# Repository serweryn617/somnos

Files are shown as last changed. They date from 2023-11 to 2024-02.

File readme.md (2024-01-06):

# Somnos

IoT USB power measurement and on/off switch.

---

The device has USB C input and standard USB A output.

It is capable of measuring USB bus voltage, current and power as well as switching the power on and off.

When requested, the measurement result can be sent over ethernet (UDP) to a receiver, for example to a PC.

⚠️ Power consumed by the device itself is also included in this measurement, which may be unwanted in some use cases.

# Building Firmware

Setup build environment:

```bash
./project.py submodules
./project.py setup
```

Build the project:

```bash
./project.py build
```

# Hardware Used

- Raspberry Pi Pico microcontroller,
- INA219 I2C Current/Power Monitor breakout board,
- Enc28J60 Ethernet Controller board,
- MOSFET breakout board,
- Custom breakout PCB,
- 3D printed enclosure and 4 M3x8 screws.

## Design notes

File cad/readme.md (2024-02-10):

# Somnos CAD Files

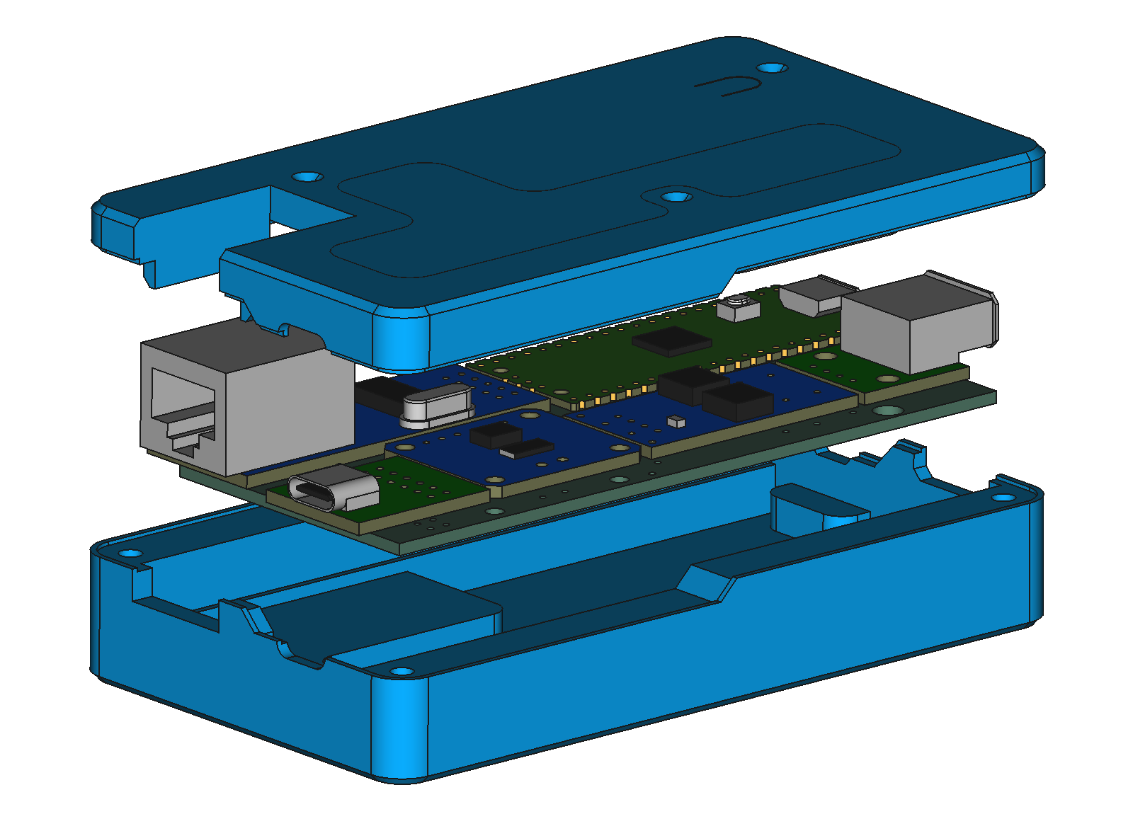
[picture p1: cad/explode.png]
explode


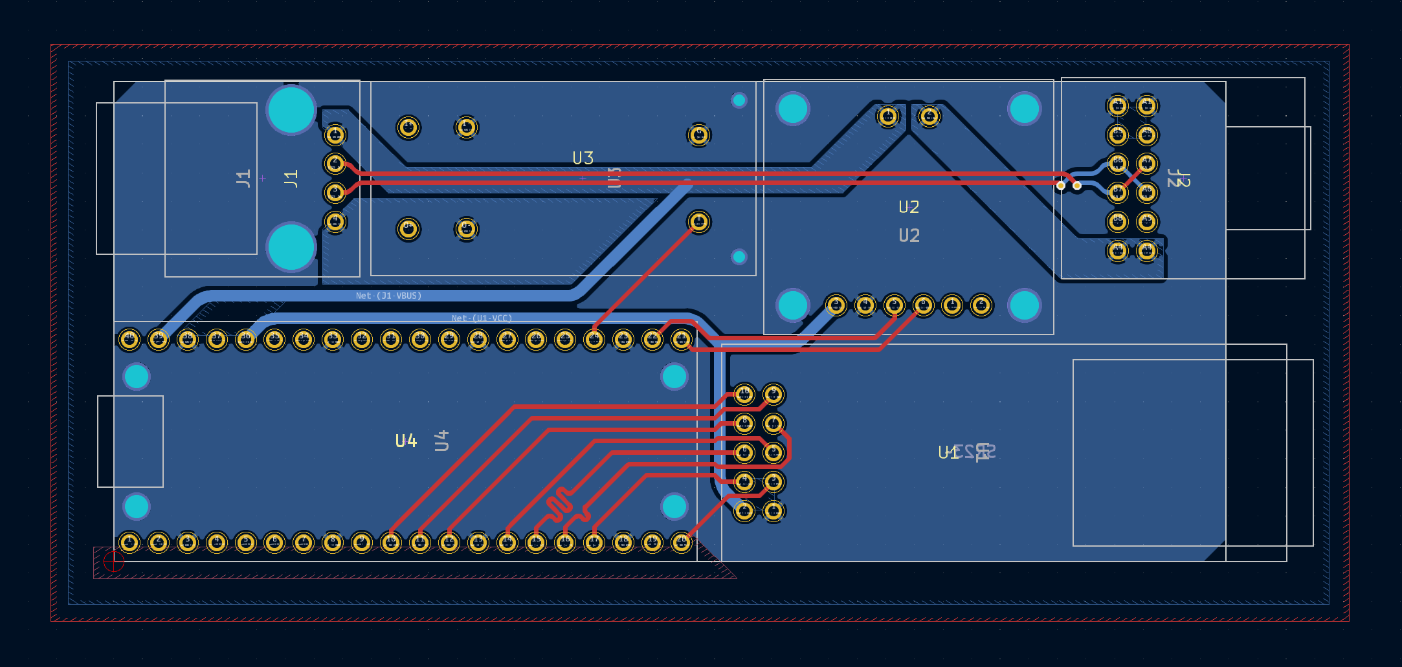
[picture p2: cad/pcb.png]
pcb


---

Initial PCB prototype notes:
 - resistors missing on USB-C CC pins!
 - update INA219 footprint so it better matches the module,
 - disconnect clkout pin - unused ethernet module output pin.

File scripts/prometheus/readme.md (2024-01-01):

# Example Prometheus Scripts

Scripts that can be used to automatically get data from the device and prepare it for [Prometheus](https://prometheus.io/).

## Usage

Display power data manually:

```bash
python3 get_power.py
```

---

Measure power every 15s using cron:

Edit crontab:

```bash
crontab -e
```

Add the following entry:

```bash
* * * * * <script path>/power.sh
```

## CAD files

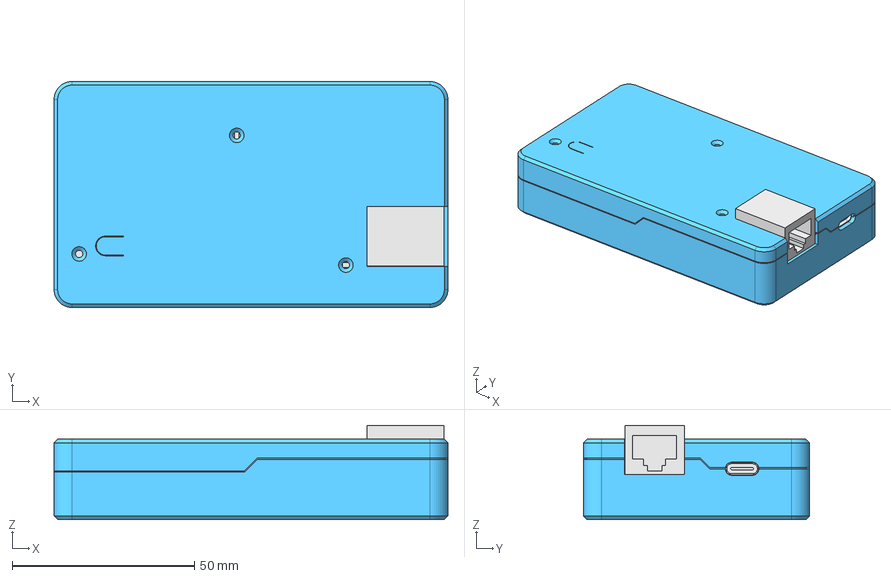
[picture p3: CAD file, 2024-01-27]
cad/freecad/assembly.FCStd
108.0 x 62.0 x 25.8 mm
pcb1_001
bottom_housing_v1.1_001
usba_001
usbc_001
ina219_001
nmos_001
enc_001
pico_001
top_housing_001
top_modifier_001

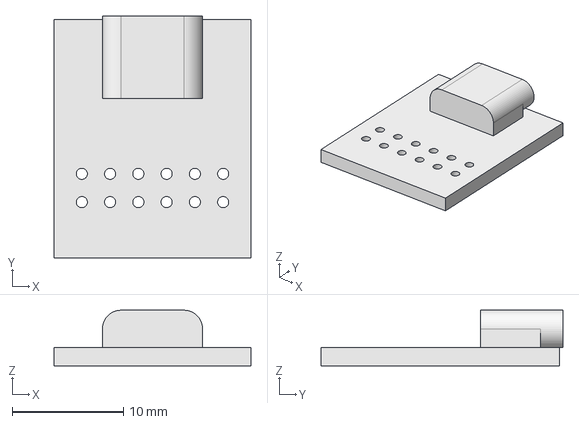
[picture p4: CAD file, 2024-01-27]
cad/freecad/usbc.FCStd
17.7 x 21.7 x 5.00 mm

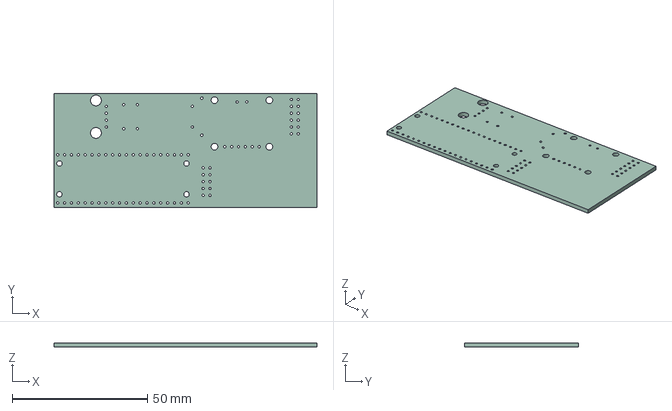
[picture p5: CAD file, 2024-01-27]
cad/kicad/project/pcb.step
97.2 x 42.0 x 1.60 mm

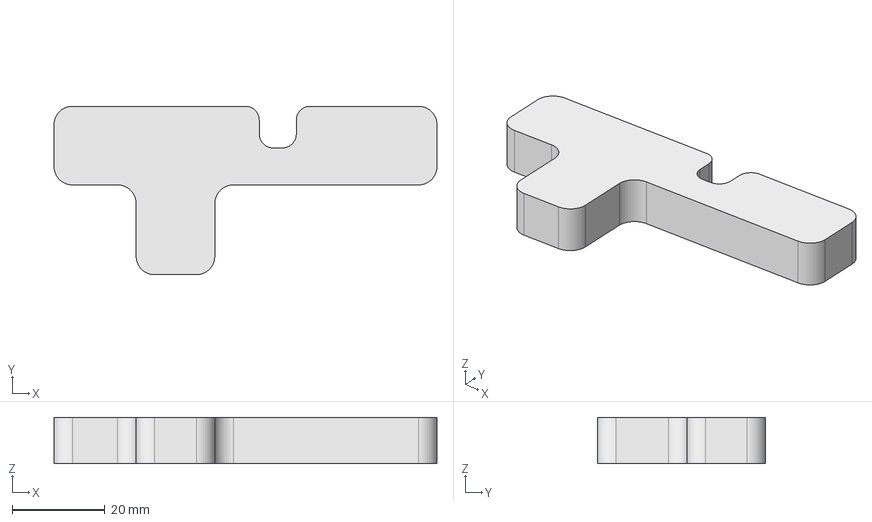
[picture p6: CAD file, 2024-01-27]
cad/top_housing_modifier.step
82.8 x 36.4 x 10.0 mm

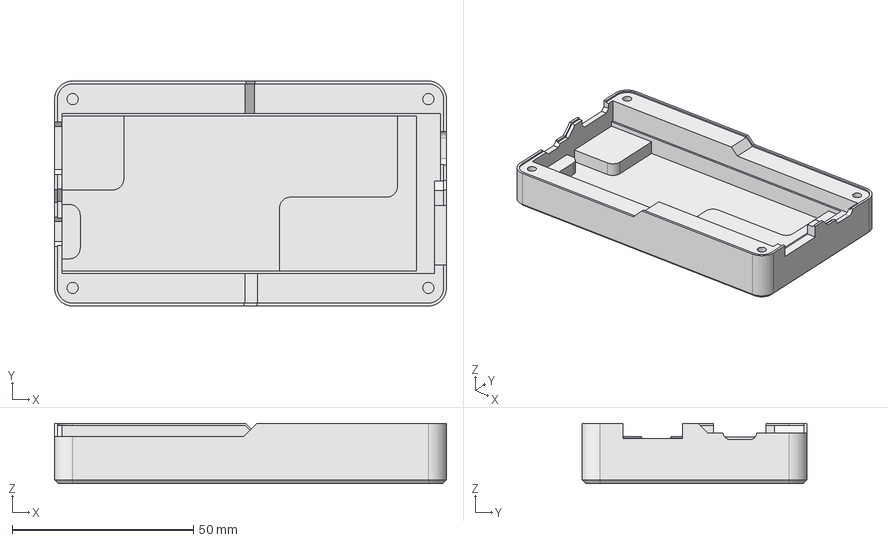
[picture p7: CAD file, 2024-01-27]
cad/bottom_housing.step
108.0 x 62.0 x 16.5 mm

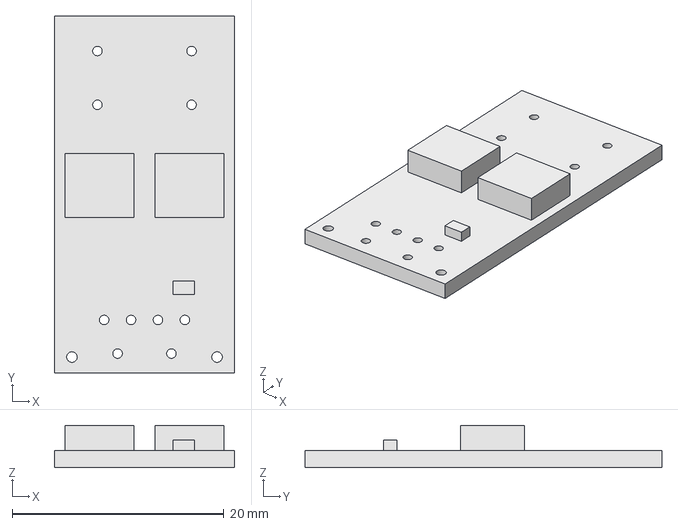
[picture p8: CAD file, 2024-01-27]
cad/freecad/nmos.FCStd
17.0 x 33.7 x 4.00 mm

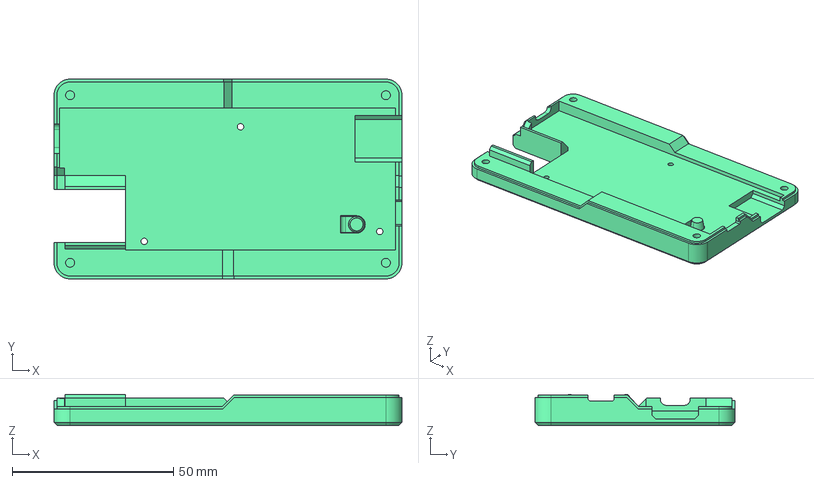
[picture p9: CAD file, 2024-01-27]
cad/top_housing.step
108.0 x 62.0 x 9.70 mm

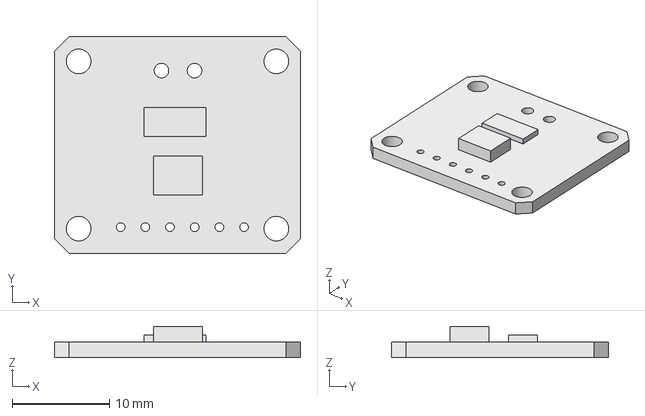
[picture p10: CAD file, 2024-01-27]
cad/freecad/ina219.FCStd
25.3 x 22.3 x 3.20 mm

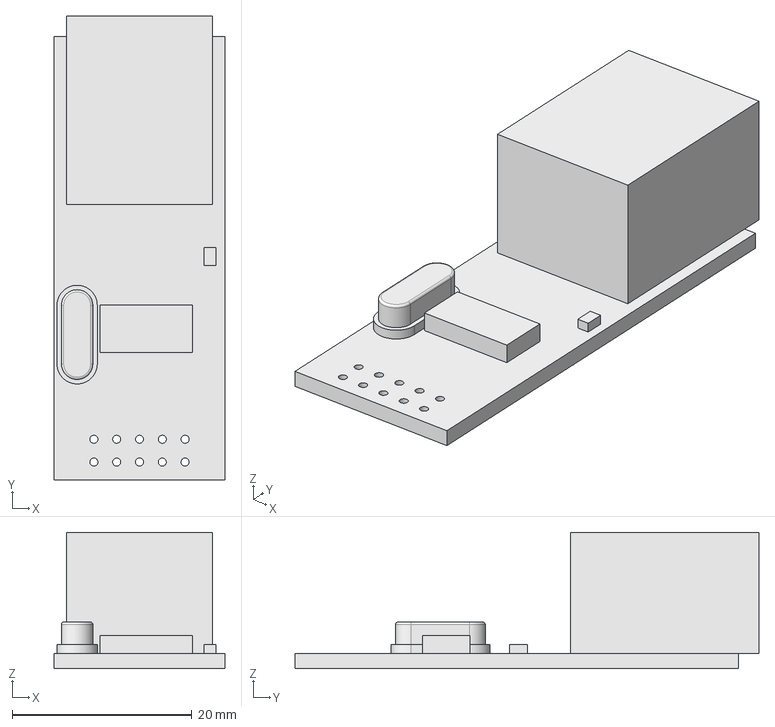
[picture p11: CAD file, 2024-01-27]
cad/freecad/enc.FCStd
19.0 x 51.7 x 15.2 mm

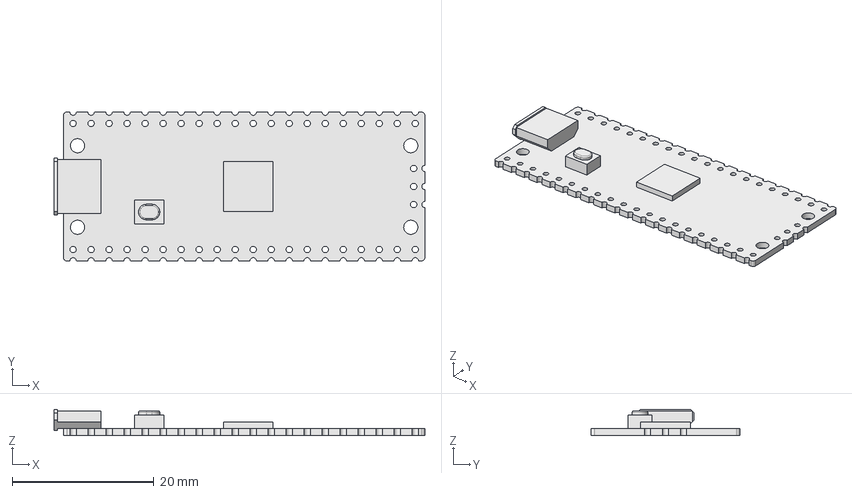
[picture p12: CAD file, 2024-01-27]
cad/freecad/pico.FCStd
52.3 x 21.0 x 3.71 mm

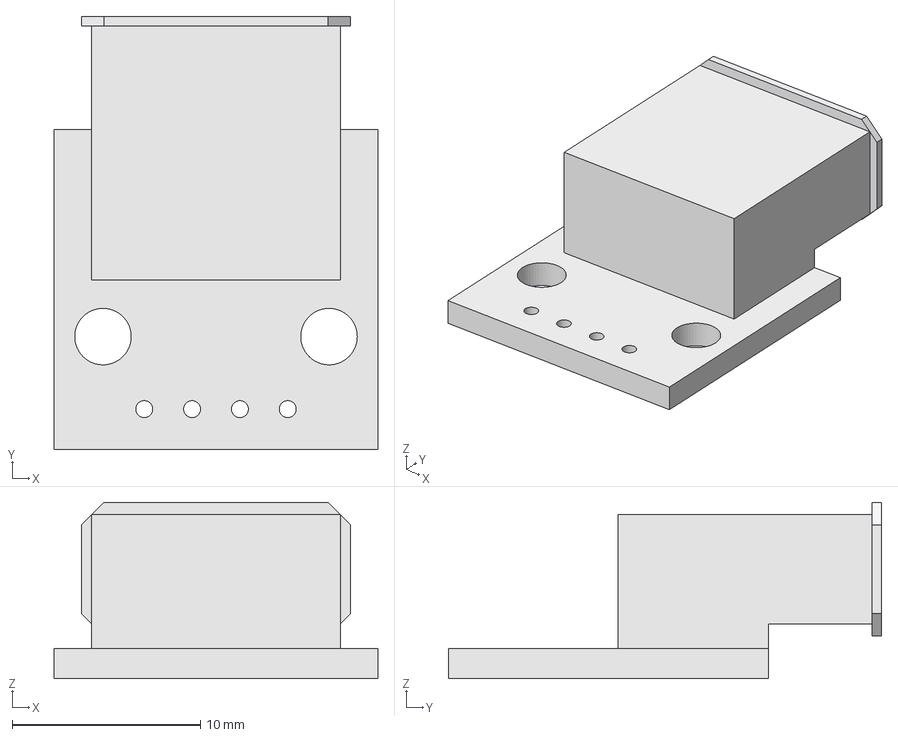
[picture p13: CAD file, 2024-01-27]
cad/freecad/usba.FCStd
17.2 x 23.0 x 9.35 mm

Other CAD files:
cad/freecad/top_modifier.FCStd
cad/freecad/bottom_housing.FCStd
cad/freecad/top_housing.FCStd

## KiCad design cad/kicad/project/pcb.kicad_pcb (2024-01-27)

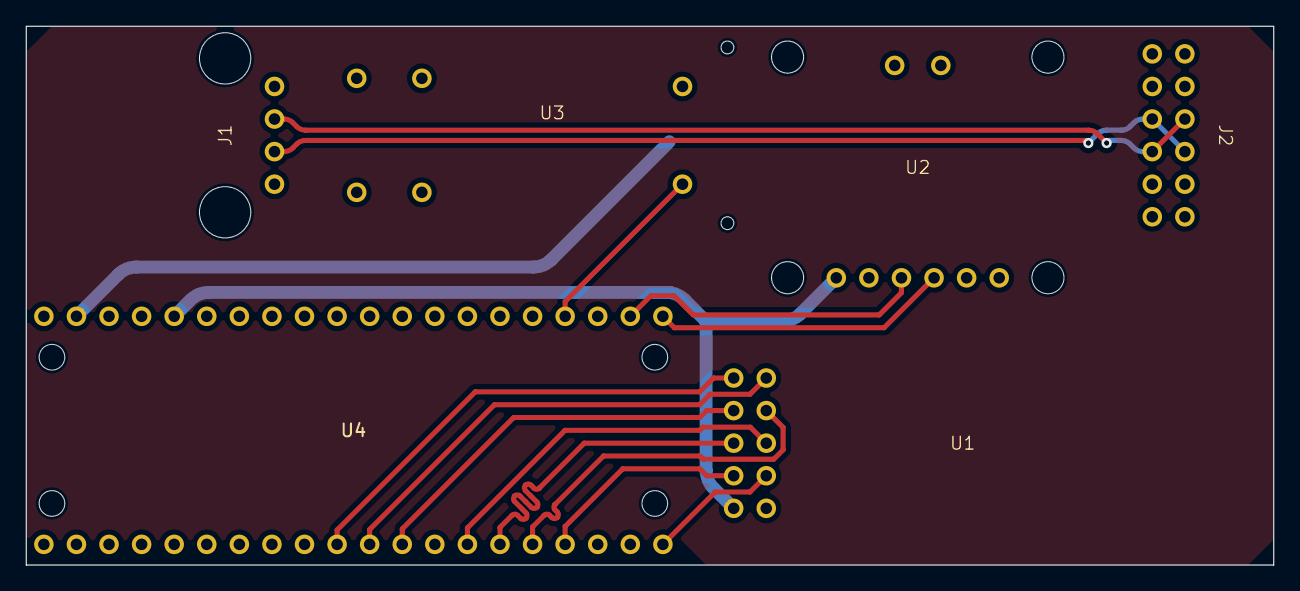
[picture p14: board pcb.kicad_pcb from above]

Board: 2 copper layers, 97.2 x 42.0 mm, 6 parts (0 on the bottom side), 18 nets.

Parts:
J1: USB_A; USB A Port
J2: USB_C_Receptacle_USB2.0; USB C Port
U1: END28J60
U2: INA219
U3: N-MOS_1
U4: PiPico

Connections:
/USB_D+: J1.3 (D+), J2.A6 (D+), J2.B6 (D+)
/USB_D-: J1.2 (D-), J2.A7 (D-), J2.B7 (D-)
unnamed: J1.4 (GND), U3.O- (VOUT-)
unnamed: J1.1 (VBUS), U2.1 (VIN-), U4.39 (VSYS)
unnamed: U1.10 (CLK), U4.10 (GP7)
unnamed: U1.4 (CS), U4.17 (GP13)
unnamed: J2.A1 (GND), U1.1 (GND), U2.4 (GND), U3.G (GND), U3.I- (VIN-), U4.3 (GND), U4.8 (GND), U4.13 (GND), U4.18 (GND), U4.23 (GND), U4.28 (GND), U4.33 (GND), U4.38 (GND)
unnamed: U1.9 (INT), U4.11 (GP8)
unnamed: U1.3 (RST), U4.20 (GP15)
unnamed: U1.5 (SCK), U4.14 (GP10)
unnamed: U1.6 (SI), U4.15 (GP11)
unnamed: U1.7 (SO), U4.16 (GP12)
unnamed: U1.2 (VCC), U2.3 (VCC), U4.36 (3V3(OUT))
unnamed: U1.8 (WOL), U4.12 (GP9)
unnamed: U2.5 (SCL), U4.22 (GP17)
unnamed: U2.6 (SDA), U4.21 (GP16)
unnamed: J2.A4 (VBUS), U2.2 (VIN+)
unnamed: U3.T (TRIG), U4.24 (GP18)

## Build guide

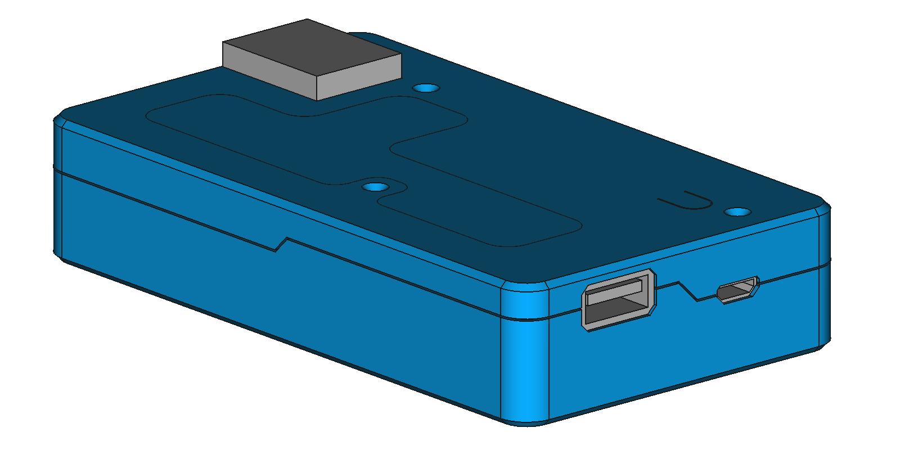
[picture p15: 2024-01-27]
cad/assembly.png

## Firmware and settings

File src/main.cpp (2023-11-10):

#include <stdio.h>

#include "lwip/inet.h"
#include "lwip/tcp.h"
#include "lwip/udp.h"
#include "lwip/netif.h"
#include "lwip/init.h"
#include "lwip/stats.h"
#include "lwip/dhcp.h"
#include "lwip/timeouts.h"
#include "netif/etharp.h"

#include "pico/stdlib.h"
#include "pico/binary_info.h"

#include <stdio.h>
#include <string.h>

#include "ina219.h"
#include "enc28j60.h"
#include "pico_i2c_driver.h"
#include "pico_spi_driver.h"

#define SPI_PORT spi1
#define PIN_SCK 10
#define PIN_MOSI 11
#define PIN_MISO 12
#define PIN_CS 13

// based on example from: https://www.nongnu.org/lwip/2_0_x/group__lwip__nosys.html
#define ETHERNET_MTU 1500

using namespace devices::enc28j60;
using namespace devices::ina219;
using namespace drivers::pico;

uint8_t mac_addr[6] = {0x11, 0xe8, 0xc3, 0xf8, 0xc6, 0x92};

PicoSPIDriver enc_driver(SPI_PORT, PIN_CS, PIN_MISO, PIN_MOSI, PIN_SCK);
Enc28j60 enc28j60(enc_driver);

struct udp_pcb* upcb;

void udp_receive_callback(void *arg, struct udp_pcb *upcb, struct pbuf *p, const ip_addr_t *addr, u16_t port){

	//struct pbuf *p;
	uint8_t data[100]={0};
      sprintf((char*)data, "sending udp client message" );
      /* allocate pbuf from pool*/
      p = pbuf_alloc(PBUF_TRANSPORT,strlen((char*)data), PBUF_POOL);
      if (p != NULL)
      {
        /* copy data to pbuf */
        pbuf_take(p, (char*)data, strlen((char*)data));

        /* send udp data */
        udp_send(upcb, p);

        /* free pbuf */
        pbuf_free(p);
      }
}

err_t create_udp_socket(){
    err_t err = ERR_OK;
    ip4_addr_t destIPAddr;
    upcb = udp_new();

    if (upcb == NULL){
        return ERR_MEM;
    }
    // Load the static IP of the destination address
    //169.254.157.160:

    // Tx_buf[30] = 192; // destination IP
//    Tx_buf[31] = 168;
//    Tx_buf[32] = 1;
//    Tx_buf[33] = 49;


    IP4_ADDR(&destIPAddr,192,168,1,26);
    upcb->local_port = 5001;
    //upcb->local_port = 4004; // Set our local port to 4004
    // Should bind to the local ip and port
    err = udp_bind(upcb,IP4_ADDR_ANY,5004);
    if (err != ERR_OK){
        return err;
    }
    // Connect to the other port
    err = udp_connect(upcb,&destIPAddr,5001);
    if (err != ERR_OK){
        return err;
    }
    // Set the receive function
    udp_recv(upcb,udp_receive_callback,NULL);
    return err;
}

err_t send_msg_to_dest(char prefix, uint16_t value){
    struct pbuf *p;
    uint8_t data[100]={0};

    data[0] = prefix;
    data[1] = value & 0xff;
    data[2] = value >> 8;

    /* allocate pbuf from pool*/
    //p = pbuf_alloc(PBUF_TRANSPORT,strlen((char*)data), PBUF_POOL);
    p = pbuf_alloc(PBUF_TRANSPORT, 3, PBUF_POOL);

    if (p != NULL)
    {
        /* copy data to pbuf */
        pbuf_take(p, (char*)data, strlen((char*)data));

        /* send udp data */
        udp_send(upcb, p);

        /* free pbuf */
        pbuf_free(p);
        return ERR_OK;
    }
    return ERR_MEM;
}






static err_t netif_output(struct netif *netif, struct pbuf *p)
{
    LINK_STATS_INC(link.xmit);

    // lock_interrupts();
    // pbuf_copy_partial(p, mac_send_buffer, p->tot_len, 0);
    /* Start MAC transmit here */

    printf("enc28j60: Sending packet of len %d\n", p->len);
    enc28j60.packet_send(p->len, (uint8_t *)p->payload);
    // pbuf_free(p);

    // // error sending
    // dral::enc28j60::common::stat stat;
    // stat.value = enc28j60.read(stat.Address, stat.RegBank);
    // if (stat.txabrt)
    // {
    //     // a seven-byte transmit status vector will be
    //     // written to the location pointed to by ETXND + 1,
    //     printf("ERR - transmit aborted\n");
    // }

    // dral::enc28j60::common::ir ir;
    // ir.value = enc28j60.read(ir.Address, ir.RegBank);
    // if (ir.txerif)
    // {
    //     printf("ERR - transmit interrupt flag set\n");
    // }

    // unlock_interrupts();
    return ERR_OK;
}

static void netif_status_callback(struct netif *netif)
{
    printf("netif status changed %s\n", ip4addr_ntoa(netif_ip4_addr(netif)));
}

static err_t netif_initialize(struct netif *netif)
{
    netif->linkoutput = netif_output;
    netif->output = etharp_output;
    // netif->output_ip6 = ethip6_output;
    netif->mtu = ETHERNET_MTU;
    netif->flags = NETIF_FLAG_BROADCAST | NETIF_FLAG_ETHARP | NETIF_FLAG_ETHERNET | NETIF_FLAG_IGMP | NETIF_FLAG_MLD6;
    // MIB2_INIT_NETIF(netif, snmp_ifType_ethernet_csmacd, 100000000);
    SMEMCPY(netif->hwaddr, mac_addr, sizeof(netif->hwaddr));
    netif->hwaddr_len = sizeof(netif->hwaddr);
    return ERR_OK;
}



int main() {
    // Enable UART so we can print status output
    stdio_init_all();

    // Make the I2C pins available to picotool
    // bi_decl(bi_2pins_with_func(PICO_DEFAULT_I2C_SDA_PIN, PICO_DEFAULT_I2C_SCL_PIN, GPIO_FUNC_I2C));

    const uint mosfet_pin = 18;
    gpio_init(mosfet_pin);
    gpio_set_dir(mosfet_pin, GPIO_OUT);
    bool sw = false;
    gpio_put(mosfet_pin, 1);

    ip_addr_t addr, mask, static_ip;
    IP4_ADDR(&static_ip, 192, 168, 1, 111);
    IP4_ADDR(&mask, 255, 255, 255, 0);
    IP4_ADDR(&addr, 192, 168, 1, 1);

    enc_driver.init();
    enc28j60.init(mac_addr);

    struct netif netif;
    lwip_init();
    // IP4_ADDR_ANY if using DHCP client
    netif_add(&netif, &static_ip, &mask, &addr, NULL, netif_initialize, netif_input);
    netif.name[0] = 'e';
    netif.name[1] = '0';
    // netif_create_ip6_linklocal_address(&netif, 1);
    // netif.ip6_autoconfig_enabled = 1;
    netif_set_status_callback(&netif, netif_status_callback);
    netif_set_default(&netif);
    netif_set_up(&netif);

    dhcp_inform(&netif);
    // dhcp_start(&netif);

    uint8_t *eth_pkt = (uint8_t*)malloc(ETHERNET_MTU);
    struct pbuf *p = NULL;

    netif_set_link_up(&netif);
    create_udp_socket();

    PicoI2CDriver ina219_driver(i2c0, 16, 17, 0x40);
    ina219_driver.init();
    INA219<PicoI2CDriver> ina219(ina219_driver);
    ina219.calibrate();

    while (true) {
        // sw = !sw;
        // sleep_ms(100);
        // gpio_put(mosfet_pin, sw);
        // sleep_ms(100);

        // float sh = ina219.shunt_voltage();
        // printf("Shunt voltage: %.2f mV\n", sh);

        // float bus = ina219.bus_voltage();
        // printf("Bus voltage: %.2f V\n", bus);

        uint16_t packet_len = enc28j60.packet_receive(ETHERNET_MTU, (uint8_t *)eth_pkt);
        if (packet_len)
        {
            printf("enc: Received packet of length = %d\n", packet_len);
            p = pbuf_alloc(PBUF_RAW, packet_len, PBUF_POOL);
            pbuf_take(p, eth_pkt, packet_len);
            free(eth_pkt);
            eth_pkt = (uint8_t*)malloc(ETHERNET_MTU);
        }
        else
        {
            // printf("enc: no packet received\n");
        }

        if (packet_len && p != NULL)
        {
            LINK_STATS_INC(link.recv);

            if (netif.input(p, &netif) != ERR_OK)
            {
                pbuf_free(p);
            }
        }

        send_msg_to_dest('B', ina219.bus_voltage_raw());
        send_msg_to_dest('S', ina219.shunt_voltage_raw());
        send_msg_to_dest('C', ina219.current_raw());

        /* Cyclic lwIP timers check */
        sys_check_timeouts();

        sleep_ms(1000);
    }

    return 0;
}

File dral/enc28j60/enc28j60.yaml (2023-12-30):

device:
  name: ENC28J60
  description: Stand-Alone Ethernet Controller with SPI Interface
  peripherals:
  - name: COMMON
    description: Common Ethernet Registers
    registers:
    - name: IE
      description: Ethernet Interrupt Enable
      size: 8
      offset: 0x1B
      reset_value: 0x00
      reg_bank: 0  # TODO: Reg bank doesn't matter for common registers
      fields:
      - name: INTIE
        description: Global INT Interrupt Enable
        position: 7
        width: 1
      - name: PKTIE
        description: Receive Packet Pending Interrupt Enable
        position: 6
        width: 1
      - name: DMAIE
        description: DMA Interrupt Enable
        position: 5
        width: 1
      - name: LINKIE
        description: Link Status Change Interrupt Enable
        position: 4
        width: 1
      - name: TXIE
        description: Transmit Enable
        position: 3
        width: 1
      - name: TXERIE
        description: Transmit Error Interrupt Enable
        position: 1
        width: 1
      - name: RXERIE
        description: Receive Error Interrupt Enable
        position: 0
        width: 1
    - name: IR
      description: Ethernet Interrupt Request (Flag)
      size: 8
      offset: 0x1C
      reset_value: 0x00
      reg_bank: 0
      fields:
      - name: PKTIF 
        description: Receive Packet Pending Interrupt Flag
        position: 6
        width: 1
      - name: DMAIF 
        description: DMA Interrupt Flag
        position: 5
        width: 1
      - name: LINKIF 
        description: Link Change Interrupt Flag
        position: 4
        width: 1
      - name: TXIF 
        description: Transmit Interrupt Flag
        position: 3
        width: 1
      - name: TXERIF 
        description: Transmit Error Interrupt Flag
        position: 1
        width: 1
      - name: RXERIF
        description: Receive Error Interrupt Flag
        position: 0
        width: 1
    - name: STAT
      description: Ethernet Status
      size: 8
      offset: 0x1D
      reset_value: 0x00
      reg_bank: 0
      fields:
      - name: INTR
        description: INT Interrupt Flag
        position: 7
        width: 1
      - name: BUFER
        description: Ethernet Buffer Error Status
        position: 6
        width: 1
      - name: LATECOL
        description: Late Collision Error
        position: 4
        width: 1
      - name: RXBUSY
        description: Receive Busy
        position: 2
        width: 1
      - name: TXABRT
        description: Transmit Abort Error
        position: 1
        width: 1
      - name: CLKRDY
        description: Clock Ready
        position: 0
        width: 1
    - name: CON2
      description: Ethernet Control Register 2
      size: 8
      offset: 0x1E
      reset_value: 0x80
      reg_bank: 0
      fields:
      - name: AUTOINC 
        description: Automatic Buffer Pointer Increment Enable
        position: 7
        width: 1
      - name: PKTDEC 
        description: Packet Decrement
        position: 6
        width: 1
      - name: PWRSV 
        description: Power Save Enable
        position: 5
        width: 1
      - name: VRPS
        description: Voltage Regulator Power Save Enable
        position: 3
        width: 1
    - name: CON1
      description: Ethernet Control Register 1
      size: 8
      offset: 0x1F
      reset_value: 0x00
      reg_bank: 0
      fields:
      - name: TXRST 
        description: Transmit Logic Reset
        position: 7
        width: 1
      - name: RXRST 
        description: Receive Logic Reset
        position: 6
        width: 1
      - name: DMAST 
        description: DMA Start and Busy Status
        position: 5
        width: 1
      - name: CSUMEN 
        description: DMA Checksum Enable
        position: 4
        width: 1
      - name: TXRTS 
        description: Transmit Request to Send
        position: 3
        width: 1
      - name: RXEN 
        description: Receive Enable
        position: 2
        width: 1
      - name: BSEL
        description: Bank Select
        position: 0
        width: 2
  - name: ETH
    description: Ethernet Control Registers
    registers:
    - name: RDPTL
      description: Read Pointer Low Byte
      size: 8
      offset: 0x00
      reset_value: 0xFA
      reg_bank: 0
      fields: []
    - name: RDPTH
      description: Read Pointer High Byte
      size: 8
      offset: 0x01
      reset_value: 0x05
      reg_bank: 0
      fields:
      - name: DATA  # TODO: How to manage such fields?
        position: 0
        width: 5
    - name: WRPTL
      description: Write Pointer Low Byte
      size: 8
      offset: 0x02
      reset_value: 0x00
      reg_bank: 0
      fields: []
    - name: WRPTH
      description: Write Pointer High Byte
      size: 8
      offset: 0x03
      reset_value: 0x00
      reg_bank: 0
      fields:
      - name: DATA
        position: 0
        width: 5
    - name: TXSTL
      description: TX Start Low Byte
      size: 8
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

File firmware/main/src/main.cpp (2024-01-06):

#include "pico/binary_info.h"
#include "pico/stdlib.h"

#include <stdio.h>
#include <string.h>

#include "devices/enc28j60/enc28j60.h"
#include "devices/ina219/ina219.h"
#include "drivers/pico/i2c/inc/pico_i2c_driver.h"
#include "drivers/pico/spi/inc/pico_spi_driver.h"

#include "main/inc/hw.h"
#include "network_interface/network_interface.h"

using namespace devices::enc28j60;
using namespace devices::ina219;
using namespace drivers::pico;
using namespace network;


struct payload {
    char magic[4] = {'S', 'M', 'N', 'S'};
    float bus;
    float shunt;
    float current;
    float power;
};


int main()
{
    stdio_init_all();

    gpio_init(hw::mosfet::pin);
    gpio_set_dir(hw::mosfet::pin, GPIO_OUT);
    gpio_put(hw::mosfet::pin, true);

    PicoI2CDriver i2c_driver(i2c0, hw::ina219::i2c::sda, hw::ina219::i2c::scl, hw::ina219::i2c::address);
    i2c_driver.init();
    INA219 ina219(i2c_driver);
    ina219.calibrate();

    uint8_t mac_addr[6] = { 0x11, 0xe8, 0xc3, 0xf8, 0xc6, 0x92 };  // TODO: remove
    PicoSPIDriver spi_driver(spi1, hw::enc28j60::spi::cs, hw::enc28j60::spi::miso, hw::enc28j60::spi::mosi, hw::enc28j60::spi::sck);
    spi_driver.init();
    Enc28j60 enc28j60(spi_driver);
    enc28j60.init(mac_addr);
    Interface network_interface(enc28j60);
    network_interface.init();

    uint8_t udp_rcv_data[10] = {0};
    network_interface.set_udp_rcv_buffer(udp_rcv_data, sizeof(udp_rcv_data));

    while (true) {
        network_interface.receive();

        if (uint16_t len = network_interface.get_udp_rcv_len(); len >= 5) {
            if (udp_rcv_data[0] == 'S' && udp_rcv_data[1] == 'M' && udp_rcv_data[2] == 'N' && udp_rcv_data[3] == 'S') {
                if (udp_rcv_data[4] == '0') {
                    gpio_put(hw::mosfet::pin, false);
                }
                if (udp_rcv_data[4] == '1') {
                    gpio_put(hw::mosfet::pin, true);
                }
                if (udp_rcv_data[4] == 'R') {
                    payload payload;
                    payload.bus = ina219.bus_voltage();
                    payload.shunt = ina219.shunt_voltage();
                    payload.current = ina219.current();
                    payload.power = ina219.power();

                    network_interface.send(reinterpret_cast<uint8_t*>(&payload), sizeof(payload));
                }
            }
        }

        network_interface.check_timers();
    }

    return 0;
}

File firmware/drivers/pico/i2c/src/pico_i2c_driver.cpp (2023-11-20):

#include "drivers/pico/i2c/inc/pico_i2c_driver.h"

namespace drivers::pico {

PicoI2CDriver::PicoI2CDriver(i2c_inst_t* i2c_inst, uint8_t pin_sda, uint8_t pin_scl, uint8_t i2c_address)
    : i2c_inst_(i2c_inst)
    , i2c_address_(i2c_address)
    , pin_sda_(pin_sda)
    , pin_scl_(pin_scl){};

void PicoI2CDriver::init()
{
    i2c_init(i2c_inst_, 100 * 1000);
    gpio_set_function(pin_sda_, GPIO_FUNC_I2C);
    gpio_set_function(pin_scl_, GPIO_FUNC_I2C);
    gpio_pull_up(pin_sda_);
    gpio_pull_up(pin_scl_);
}

int PicoI2CDriver::read_data(uint8_t* buffer, uint8_t length)
{
    return i2c_read_blocking(i2c_inst_, i2c_address_, buffer, length, false);
}

int PicoI2CDriver::write_data(const uint8_t* buffer, uint8_t length)
{
    return i2c_write_blocking(i2c_inst_, i2c_address_, buffer, length, false);
}

}  // namespace drivers::pico

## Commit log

2023-11-01 I2C cleanup
2023-11-03 Ignore CAD files
2023-11-05 Massive development branch merge (#2)
    * initial enc28j60 template
    * Sort out enc28j60 template
    * Send UDP packets
    * Update pin and interface numbers
    * Add clang-format initial
    * Add pico-sdk submodule
    * Add picotool submodule
    * Update build system
    * Move enc28j60 to D-RAL
    * Fix MAC address order
    * Add D-RAL submodule
    * Update ENC28J60 D-RAL
    * Add PHY regs
    * INA219 rewrite
    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
    [enc28j60.h, enc28j60.yaml, ina219.h]
2023-11-10 ENC28J60 rewrite (#3)
    * Fix SPI CS
    * enc rewrite and namespace madness
    * Enums rework
    [enc28j60.h, enc28j60.yaml, main.cpp]
2023-11-10 Create driver definitions
2023-11-11 Fix SPI port number
    [main.cpp]
2023-11-19 Network interface initial rework (#4)
    * Network interface rewrite in progress
    * Fix SPI port number
    * Fix mistakes
    * Change some names
    * Autoformat
    * lwIP working in OOP paradigm
    * Name change
    * Quick format; added lwip reference link
    * Further network interface cleanup
    * UDP receive investigated
    * Fix UDP bidirectional traffic
    [enc28j60.h, main.cpp]
2023-12-31 INA219 new configuration and fixes
    [ina219.h, main.cpp]
2024-01-06 Move MOSFET pin to hw
2024-01-27 Add CAD data
    [assembly.FCStd, bottom_housing.FCStd, bottom_housing.step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]
2024-01-30 Update to mainline D-RAL v0.5.1 (#9)
    * Remove dral fork
    * Use mainline D-RAL
    * Peripheral base address workaround
    * Re-generate D-RAL
    [register_model.h]
